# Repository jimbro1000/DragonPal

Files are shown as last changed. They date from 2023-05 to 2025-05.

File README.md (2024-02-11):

# PAL VIDEO BOARD FOR DRAGON 32 RECREATION Rev 3 #

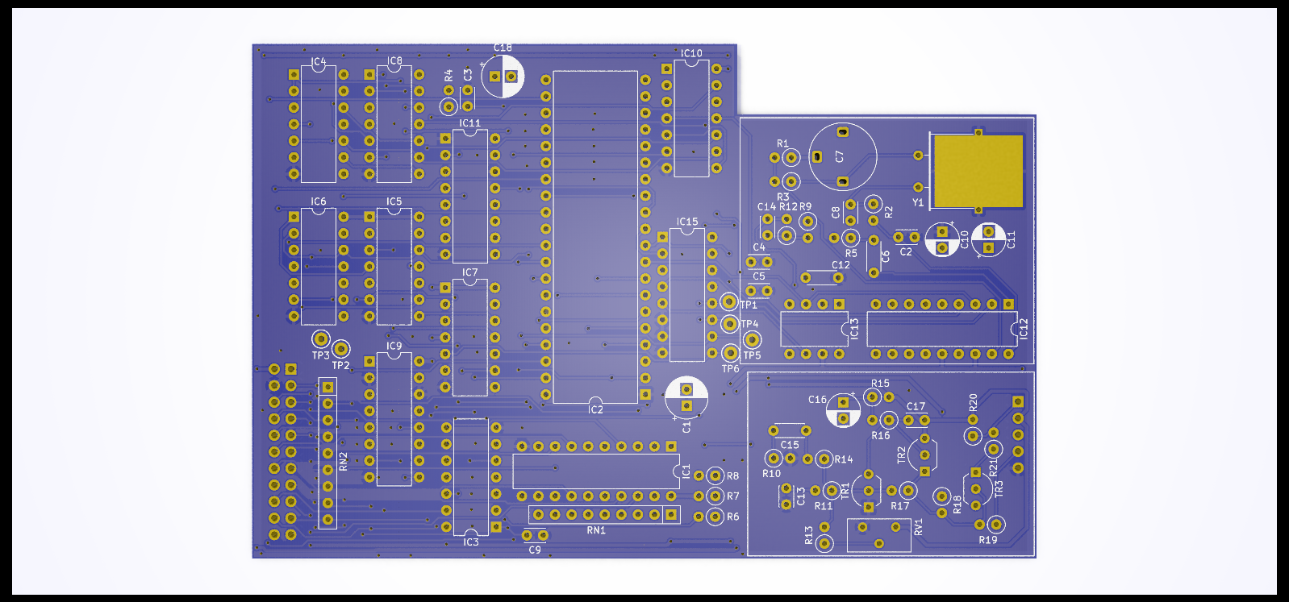
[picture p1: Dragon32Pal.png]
render of dragon 32 pal board


To further improve video quality on the Dragon 32 this
board completely isolates the video circuits from the rest
of the Dragon by making it a plugin. This also means that
only a single version of the Dragon 32 board is needed to
provide a PAL or NTSC solution.

## Progress ##

This is a complete first hack at the design, while the
schematics are trusted the layout and organisation of the
line pulse logic is very much experimental.

The clock generator and analogue circuits are completely
isolated. The ground plane on the analogue side of the board 
is as complete and uniform as possible.

## To Do ##

Adopt the Dragon 64 voltage bias circuit for the output
signal

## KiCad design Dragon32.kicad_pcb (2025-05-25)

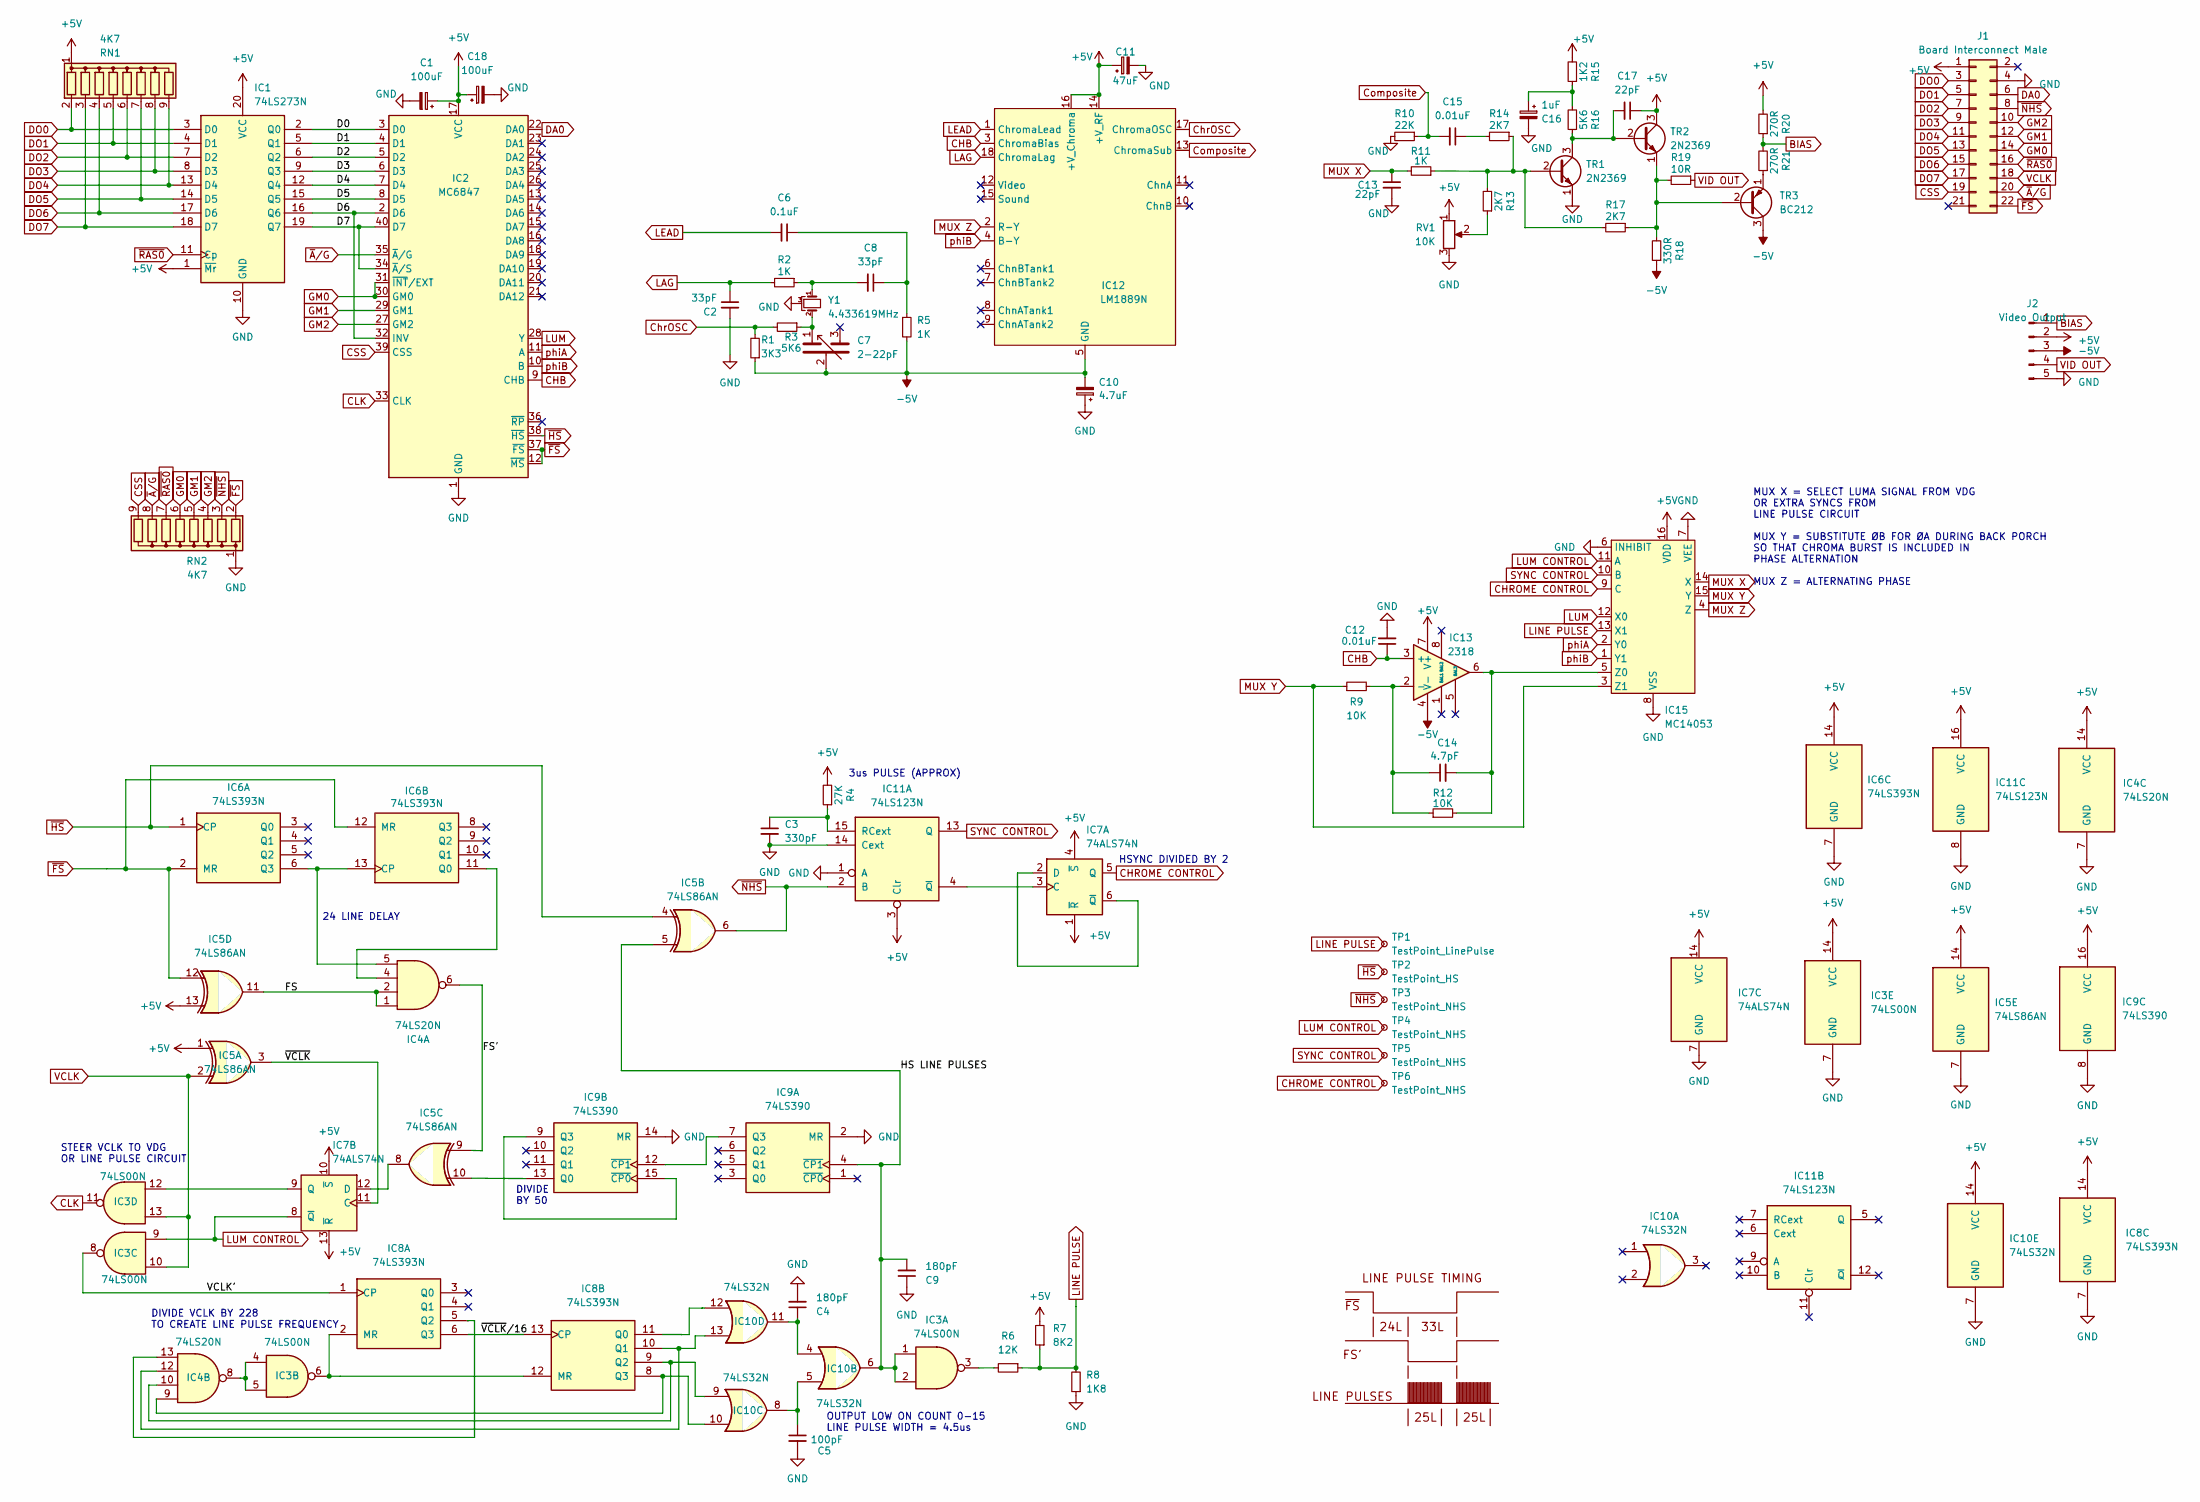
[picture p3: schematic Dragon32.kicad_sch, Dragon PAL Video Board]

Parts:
C1, C18: 100uF; CP_Radial_D6.3mm_P2.50mm; DigiKey 732-8598-1-ND
C2, C8: 33pF; C_Disc_D3.0mm_W2.0mm_P2.50mm; DigiKey BC1007CT-ND
C3: 330pF; C_Disc_D3.0mm_W2.0mm_P2.50mm; DigiKey BC1045CT-ND
C4, C9: 180pF; C_Disc_D3.0mm_W2.0mm_P2.50mm; DigiKey BC1016CT-ND
C5: 100pF; C_Disc_D3.0mm_W2.0mm_P2.50mm; DigiKey 399-C316C101J5G5TA7303CT-ND
C6: 0.1uF; C_Disc_D4.3mm_W1.9mm_P5.00mm; DigiKey BC1101CT-ND
C7: 2-22pF; Trimmer-7.5mm
C10: 4.7uF; CP_Radial_D5.0mm_P2.50mm; DigiKey 478-8984-1-ND
C11: 47uF; CP_Radial_D5.0mm_P2.50mm; DigiKey 478-8984-1-ND
C12, C15: 0.01uF; C_Disc_D4.3mm_W1.9mm_P5.00mm; DigiKey BC2662CT-ND
C13, C17: 22pF; C_Disc_D3.0mm_W2.0mm_P2.50mm; DigiKey 399-13930-1-ND
C14: 4.7pF; C_Disc_D3.0mm_W2.0mm_P2.50mm; DigiKey 445-180473-1-ND
C16: 1uF; CP_Radial_D5.0mm_P2.50mm; DigiKey 732-8966-1-ND
IC1: 74LS273N; DIP-20_W7.62mm; DigiKey 296-1657-5-ND
IC2: MC6847; DIP-40_W15.24mm
IC3: 74LS00N; DIP-14_W7.62mm; DigiKey 296-1626-ND
IC4: 74LS20N; DIP-14_W7.62mm; DigiKey 296-3670-5-ND
IC5: 74LS86AN; DIP-14_W7.62mm; DigiKey 296-1669-5-ND
IC6, IC8: 74LS393N; DIP-14_W7.62mm; DigiKey 296-1665-5-ND
IC7: 74ALS74N; DIP-14_W7.62mm; DigiKey 296-1506-5-ND
IC9: 74LS390; DIP-16_W7.62mm; DigiKey 296-26516-5-ND
IC10: 74LS32N; DIP-14_W7.62mm; DigiKey 296-1658-5-ND
IC11: 74LS123N; DIP-16_W7.62mm; DigiKey 296-1636-5-ND
IC12: LM1889N; DIP-18_W7.62mm
IC13: 2318; DIP-8_W7.62mm; DigiKey MCP6281-E/P-ND
IC15: MC14053; DIP-16_W7.62mm; DigiKey 296-2059-ND
J1: Board Interconnect Male; PinHeader_2x11_P2.54mm_Vertical
J2: Video Output; PinHeader_1x05_P2.54mm_Vertical
R1: 3K3; R_Axial_DIN0207_L6.3mm_D2.5mm_P2.54mm_Vertical; DigiKey CF14JT3K30CT-ND
R2, R5, R11: 1K; R_Axial_DIN0207_L6.3mm_D2.5mm_P2.54mm_Vertical; DigiKey CF14JT1K00CT-ND
R3, R16: 5K6; R_Axial_DIN0207_L6.3mm_D2.5mm_P2.54mm_Vertical; DigiKey CF14JT5K60CT-ND
R4: 27K; R_Axial_DIN0207_L6.3mm_D2.5mm_P2.54mm_Vertical; DigiKey CF14JT27K0CT-ND
R6: 12K; R_Axial_DIN0207_L6.3mm_D2.5mm_P2.54mm_Vertical; DigiKey CF14JT15K0CT-ND
R7: 8K2; R_Axial_DIN0207_L6.3mm_D2.5mm_P2.54mm_Vertical; DigiKey CF14JT6K80CT-ND
R8: 1K8; R_Axial_DIN0207_L6.3mm_D2.5mm_P2.54mm_Vertical; DigiKey CF14JT3K30CT-ND
R9, R12: 10K; R_Axial_DIN0207_L6.3mm_D2.5mm_P2.54mm_Vertical; DigiKey CF14JT10K0CT-ND
R10: 22K; R_Axial_DIN0207_L6.3mm_D2.5mm_P2.54mm_Vertical; DigiKey CF14JT22K0CT-ND
R13, R14, R17: 2K7; R_Axial_DIN0207_L6.3mm_D2.5mm_P2.54mm_Vertical; DigiKey CF14JT2K70CT-ND
R15: 1K2; R_Axial_DIN0207_L6.3mm_D2.5mm_P2.54mm_Vertical; DigiKey CF14JT1K20CT-ND
R18: 330R; R_Axial_DIN0207_L6.3mm_D2.5mm_P2.54mm_Vertical; DigiKey CF14JT330RCT-ND
R19: 10R; R_Axial_DIN0207_L6.3mm_D2.5mm_P2.54mm_Vertical; DigiKey CF14JT10R0CT-ND
R20, R21: 270R; R_Axial_DIN0207_L6.3mm_D2.5mm_P2.54mm_Vertical; DigiKey CF14JT270RCT-ND
RN1, RN2: 4K7; R_Array_SIP9
RV1: 10K; Potentiometer_Bourns_3386X_Horizontal; DigiKey 3386H-103LF-ND
TP1: TestPoint_LinePulse; TestPoint_Keystone_5000-5004_Miniature
TP2: TestPoint_HS; TestPoint_Keystone_5000-5004_Miniature
TP3, TP4, TP5, TP6: TestPoint_NHS; TestPoint_Keystone_5000-5004_Miniature
TR1, TR2: 2N2369; TO-92_Inline_Wide; DigiKey 2N4401D26ZCT-ND
TR3: BC212; TO-92_Inline_Wide; DigiKey 2N3906D26ZCT-ND
Y1: 4.433619MHz; Crystal_HC49-U_Horizontal_1EP_style2
Z1: LINE_PULSE_DIAGRAM

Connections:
+5V: C1.1, C11.1, C17.1, C18.1, IC1.1 (~Mr), IC1.20 (VCC), IC2.17 (VCC), IC3.14 (VCC), IC4.14 (VCC), IC5.1, IC5.13, IC5.14 (VCC), IC6.14 (VCC), IC7.1 (~R), IC7.4 (~S), IC7.10 (~S), IC7.13 (~R), IC7.14 (VCC), IC8.14 (VCC), IC9.16 (VCC), IC10.14 (VCC), IC11.3 (Clr), IC11.16 (VCC), IC12.14 (+V_RF), IC12.16 (+V_Chroma), IC13.7 (V+), IC15.16 (VDD), J1.1, J2.2, R4.2, R7.2, R15.2, R20.2, RN1.1 (common), RV1.1, TR2.3 (C)
-5V: C7.2, C10.2, IC12.5 (GND), IC13.4 (V-), J2.3, R1.1, R5.2, R18.1, TR3.3 (C)
/D0: IC1.2 (Q0), IC2.3 (D0)
/D1: IC1.5 (Q1), IC2.4 (D1)
/D2: IC1.6 (Q2), IC2.5 (D2)
/D3: IC1.9 (Q3), IC2.6 (D3)
/D4: IC1.12 (Q4), IC2.7 (D4)
/D5: IC1.15 (Q5), IC2.8 (D5)
/D6: IC1.16 (Q6), IC2.2 (D6), IC2.32 (INV)
/D7: IC1.19 (Q7), IC2.34 (~A/S), IC2.40 (D7)
/FS': IC4.6, IC5.9
/HS LINE PULSES: C9.2, IC3.1, IC3.2, IC5.5, IC9.4 (~CP1), IC10.6
/VCLK': IC3.8, IC8.1 (CP)
/~VCLK: IC5.3, IC7.11 (C)
/~VCLK/16: IC8.6 (Q3), IC8.13 (CP)
BIAS: J2.1, R20.1, R21.2
CHB: C12.1, IC2.9 (CHB), IC12.3 (ChromaBias), IC13.3 (+)
CHROME CONTROL: IC7.5 (Q), IC15.9 (C), TP6.1
CLK: IC2.33 (CLK), IC3.11
CSS: IC2.39 (CSS), J1.19, RN2.9 (R8)
ChrOSC: IC12.17 (ChromaOSC), R1.2, R3.2
Composite: C15.2, IC12.13 (ChromaSub), R10.1
DA0: IC2.22 (DA0), J1.6
DO0: IC1.3 (D0), J1.3, RN1.2 (R1)
DO1: IC1.4 (D1), J1.5, RN1.5 (R4)
DO2: IC1.7 (D2), J1.7, RN1.6 (R5)
DO3: IC1.8 (D3), J1.9, RN1.8 (R7)
DO4: IC1.13 (D4), J1.11, RN1.9 (R8)
DO5: IC1.14 (D5), J1.13, RN1.7 (R6)
DO6: IC1.17 (D6), J1.15, RN1.4 (R3)
DO7: IC1.18 (D7), J1.17, RN1.3 (R2)
GM0: IC2.30 (GM0), IC2.31 (~INT/EXT), J1.14, RN2.6 (R5)
GM1: IC2.29 (GM1), J1.12, RN2.5 (R4)
GM2: IC2.27 (GM2), J1.10, RN2.4 (R3)
GND: C1.2, C2.2, C3.2, C4.2, C5.2, C9.1, C10.1, C11.2, C12.2, C13.2, C16.2, C18.2, IC1.10 (GND), IC2.1 (GND), IC3.7 (GND), IC4.7 (GND), IC5.7 (GND), IC6.7 (GND), IC7.7 (GND), IC8.7 (GND), IC9.2 (MR), IC9.8 (GND), IC9.14 (MR), IC10.7 (GND), IC11.1 (A), IC11.8 (GND), IC11.14 (Cext), IC15.6 (INHIBIT), IC15.7 (VEE), IC15.8 (VSS), J1.4, J2.5, R8.1, R10.2, RN2.1 (common), RV1.3, TR1.1 (E), Y1.3
LAG: C2.1, IC12.18 (ChromaLag), R2.2
LEAD: C6.2, IC12.1 (ChromaLead)
LINE PULSE: IC15.13 (X1), R6.1, R7.1, R8.2, TP1.1
LUM: IC2.28 (Y), IC15.12 (X0)
LUM CONTROL: IC3.9, IC7.8 (~Q), IC15.11 (A), TP4.1
MUX X: C13.1, IC15.14 (X), R11.2
MUX Y: IC15.3 (Z1), IC15.15 (Y), R9.1
MUX Z: IC12.2 (R-Y), IC15.4 (Z)
unnamed: C4.1, IC10.4, IC10.11
unnamed: C5.1, IC10.5, IC10.8
unnamed: C6.1, C8.1, R5.1
unnamed: C7.1, R3.1, Y1.2
unnamed: C8.2, R2.1, Y1.1
unnamed: C15.1, R14.2
unnamed: C16.1, R15.1, R16.2
unnamed: IC3.3, R6.2
unnamed: IC3.4, IC3.5, IC4.8
unnamed: IC4.1, IC4.2, IC5.11
unnamed: IC4.5, IC6.6 (Q3), IC6.13 (CP)
unnamed: IC4.4, IC6.11 (Q0)
unnamed: IC7.2 (D), IC7.6 (~Q)
unnamed: IC5.8, IC7.12 (D)
unnamed: IC3.12, IC7.9 (Q)
unnamed: IC3.6, IC8.2 (MR), IC8.12 (MR)
unnamed: IC4.13, IC8.5 (Q2)
unnamed: IC8.11 (Q0), IC10.12
unnamed: IC4.12, IC8.10 (Q1), IC10.13
unnamed: IC4.10, IC8.9 (Q2), IC10.9
unnamed: IC4.9, IC8.8 (Q3), IC10.10
unnamed: IC9.7 (Q3), IC9.12 (~CP1)
unnamed: IC5.10, IC9.13 (Q0)
unnamed: IC9.9 (Q3), IC9.15 (~CP0)
unnamed: C3.1, IC11.15 (RCext), R4.1
unnamed: IC7.3 (C), IC11.4 (~Q)
unnamed: C14.1, IC13.2 (-), R9.2, R12.1
unnamed: C14.2, IC13.6, IC15.5 (Z0), R12.2
unnamed: R13.1, RV1.2
unnamed: R11.1, R13.2, R14.1, R17.2, TR1.2 (B)
unnamed: C17.2, R16.1, TR1.3 (C), TR2.2 (B)
unnamed: R17.1, R18.2, R19.2, TR2.1 (E), TR3.2 (B)
unnamed: R21.1, TR3.1 (E)
SYNC CONTROL: IC11.13 (Q), IC15.10 (B), TP5.1
VCLK: IC3.10, IC3.13, IC5.2, J1.18
VID OUT: J2.4, R19.1
phiA: IC2.11 (A), IC15.2 (Y0)
phiB: IC2.10 (B), IC12.4 (B-Y), IC15.1 (Y1)
~A/G: IC2.35 (~A/G), J1.20, RN2.8 (R7)
~FS: IC2.12 (~MS), IC2.37 (~FS), IC5.12, IC6.2 (MR), IC6.12 (MR), J1.22, RN2.2 (R1)
~HS: IC2.38 (~HS), IC5.4, IC6.1 (CP), TP2.1
~NHS: IC5.6, IC11.2 (B), J1.8, RN2.3 (R2), TP3.1
~RAS0: IC1.11 (Cp), J1.16, RN2.7 (R6)

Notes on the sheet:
24 LINE DELAY
MUX X = SELECT LUMA SIGNAL FROM VDG OR EXTRA SYNCS FROM LINE PULSE CIRCUIT MUX Y = SUBSTITUTE ØB FOR ØA DURING BACK PORCH SO THAT CHROMA BURST IS INCLUDED IN PHASE ALTERNATION MUX Z = ALTERNATING PHASE
3us PULSE (APPROX)
HSYNC DIVIDED BY 2
DIVIDE BY 50
DIVIDE VCLK BY 228 TO CREATE LINE PULSE FREQUENCY
STEER VCLK TO VDG OR LINE PULSE CIRCUIT
OUTPUT LOW ON COUNT 0-15 LINE PULSE WIDTH = 4.5us

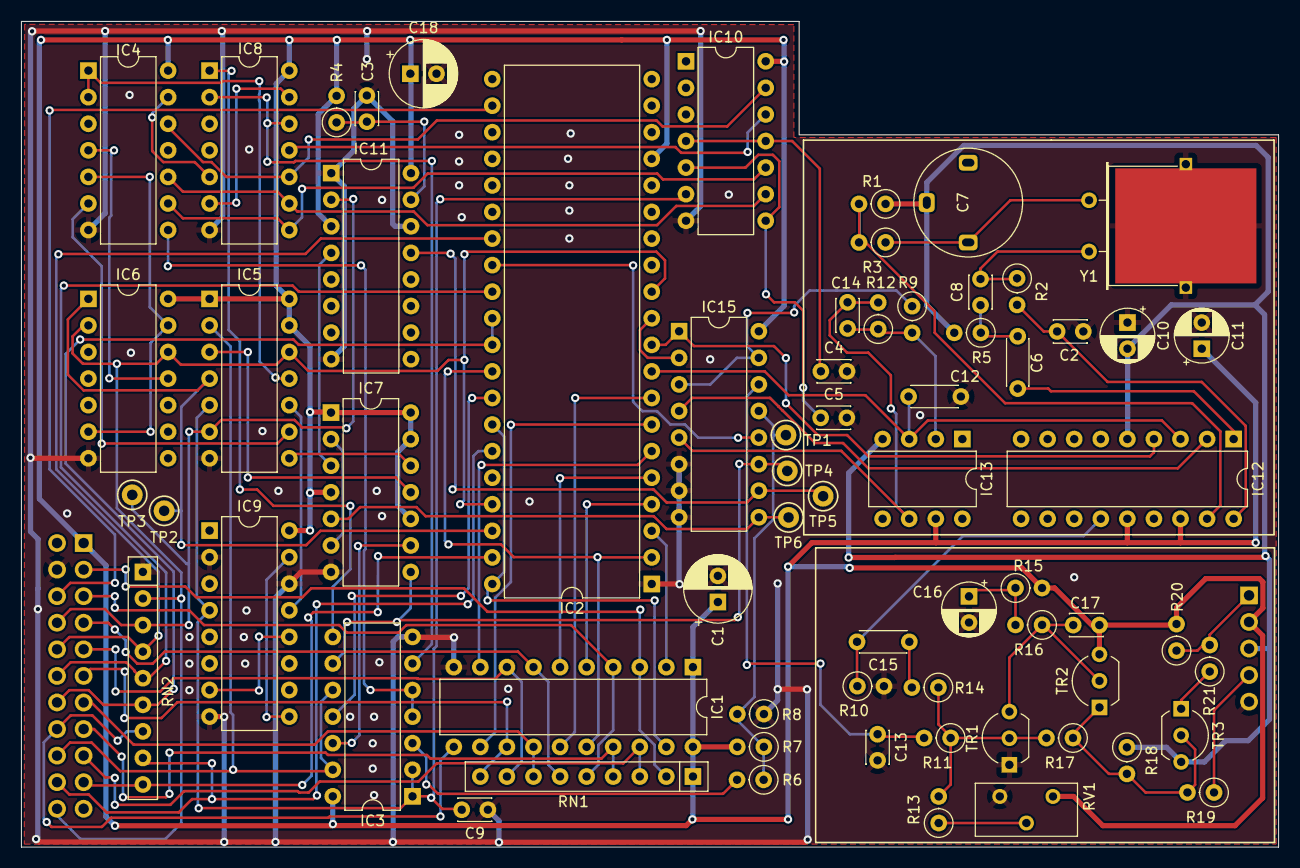
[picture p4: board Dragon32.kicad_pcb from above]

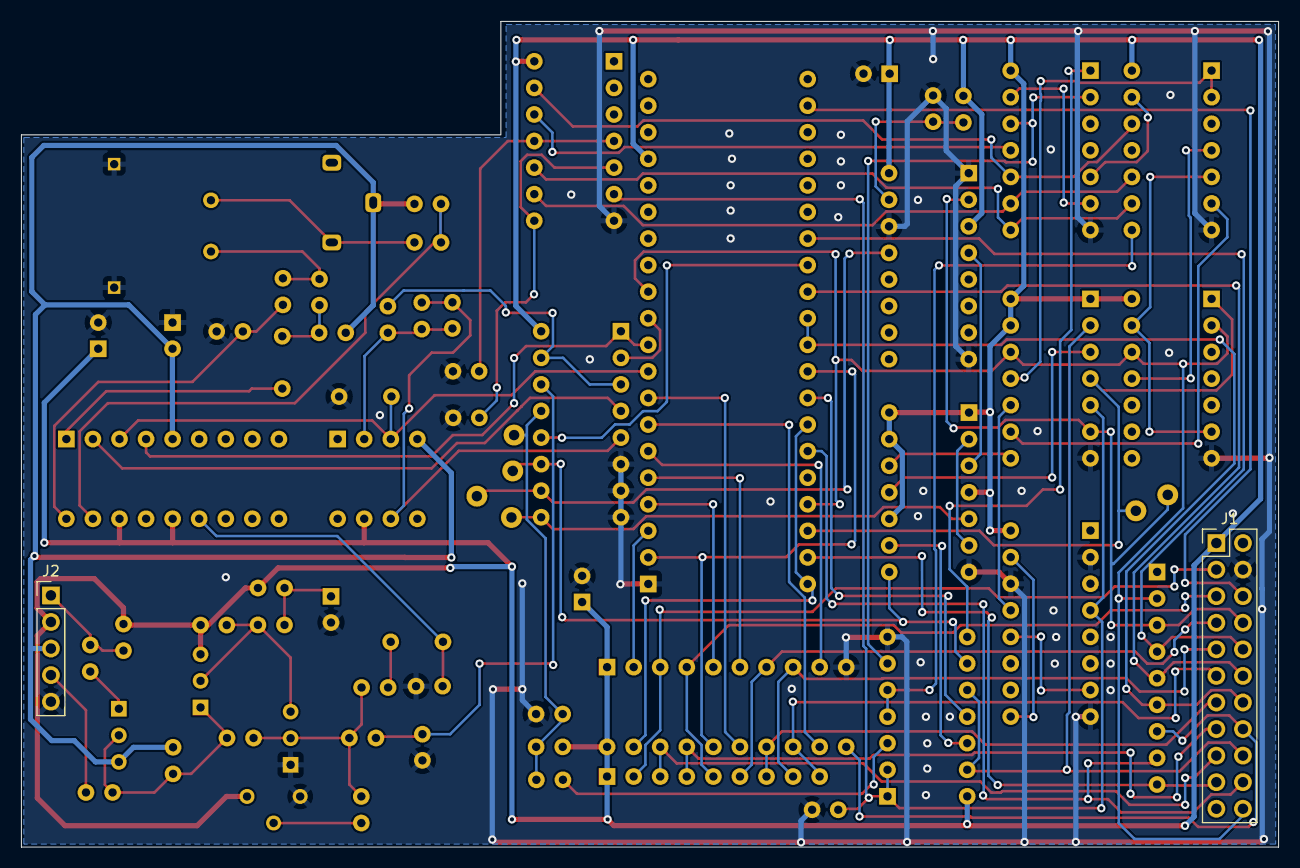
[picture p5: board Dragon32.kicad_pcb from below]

Board: 2 copper layers, 120.2 x 78.9 mm, 68 parts (2 on the bottom side), 86 nets.

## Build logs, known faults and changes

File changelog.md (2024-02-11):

# Revision 3.1 #
# Unpublished

* Extract PAL video circuit from rev 2 CPU board

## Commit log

2023-06-01 fix missing css and fs signals
    [Dragon32.kicad_pcb, Dragon32.kicad_sch]
2023-06-10 fix diff amp wiring
    [Dragon32.kicad_pcb, Dragon32.kicad_sch]
2024-02-11 notch edge of board for clearance of relay
    [Dragon32.kicad_pcb]
2024-03-04 move -5v
    [Dragon32.kicad_pcb, Dragon32.kicad_sch]
